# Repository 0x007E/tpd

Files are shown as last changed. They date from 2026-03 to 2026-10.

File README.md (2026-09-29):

  

# `TPD` - Touchpad



The `TPD` is a board with six single pads that are connected to a [AT42QT1070](#additional-information) touch sensor. The touch sensor can be connected to any microntroller over `TWI`. The board itself can be driven with a voltage from `1V8-5V` and controlled over the [AT42QTXXXX driver library](https://github.com/0x007E/drivers-touch-at42qtxxxx).

| Experience  | Level |
|:---|:---:|
| Soldering | ?% |
| Mechanical  | ?% |

# Downloads

| Type | File | Description |
|:---:|:---:|:---|
| Schematic | [pdf](https://github.com/0x007E/tpd/releases/latest/download/schematic.pdf) / [cadlab](https://cadlab.io/project/30134/main/files) | Schematic files |
| Board | [pdf](https://github.com/0x007E/tpd/releases/latest/download/pcb.pdf) / [cadlab](https://cadlab.io/project/30134/main/files) | Board file |
| Drill | [pdf](https://github.com/0x007E/tpd/releases/latest/download/drill.pdf) | Drill file |
| BoM | [xlsx](https://github.com/0x007E/tpd/releases/latest/download/bom.xlsx) / [html](https://github.com/0x007E/tpd/releases/latest/download/ibom.html) | Bill of Material as Excel/interactive HTML |
| PCB | [zip](https://github.com/0x007E/tpd/releases/latest/download/kicad.zip) / [tar](https://github.com/0x007E/tpd/releases/latest/download/kicad.tar.gz) | KiCAD/Gerber/BoM/Drill files |
| Mechanical | [zip](https://github.com/0x007E/tpd/releases/latest/download/freecad.zip) / [tar](https://github.com/0x007E/tpd/releases/latest/download/freecad.tar.gz) | FreeCAD/Housing and PCB (STEP/STL) files |

# Hardware

The pcb is created with `KiCAD`. All files are built with `github actions` so that they are ready for a production environment.

## PCB

The circuit board is populated on one side (Bottom). The best way for soldering the `SMD` components is within a vapor phase soldering system.

### Top Layer

Top Layer

### Bottom Layer

Bottom Layer

## Mechanical

The housing has a tolerance of `0.2mm` on each side of the case. So the pcb should fit perfectly in the housing. The tolerance can be modified with `FreeCAD` in the `Parameter` Spreadsheet.

### Assembled

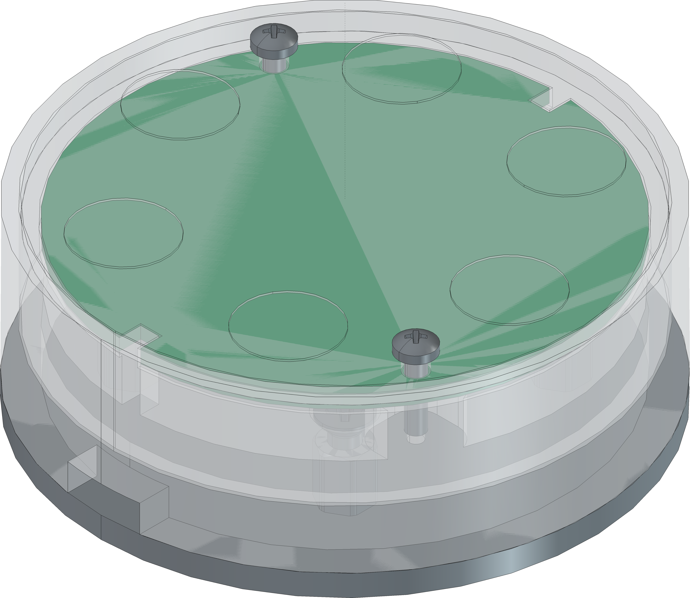
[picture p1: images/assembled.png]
Assembled


### Exploded

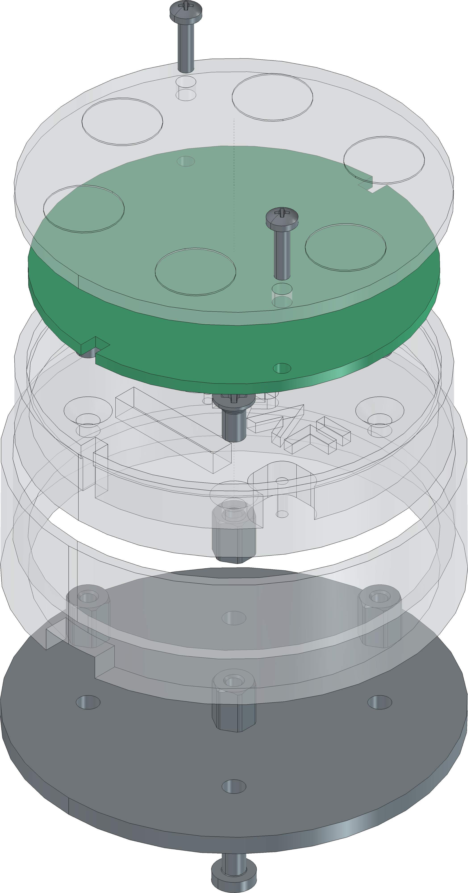
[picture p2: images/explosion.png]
Exploded


# Additional Information

| Type | Link | Description |
|:---:|:---:|:---|
| AT42QT1070 | [pdf](https://ww1.microchip.com/downloads/en/DeviceDoc/Atmel-9596-AT42-QTouch-BSW-AT42QT1070_Datasheet.pdf) | Seven-channel QTouch® Touch Sensor IC |

---

R. GAECHTER

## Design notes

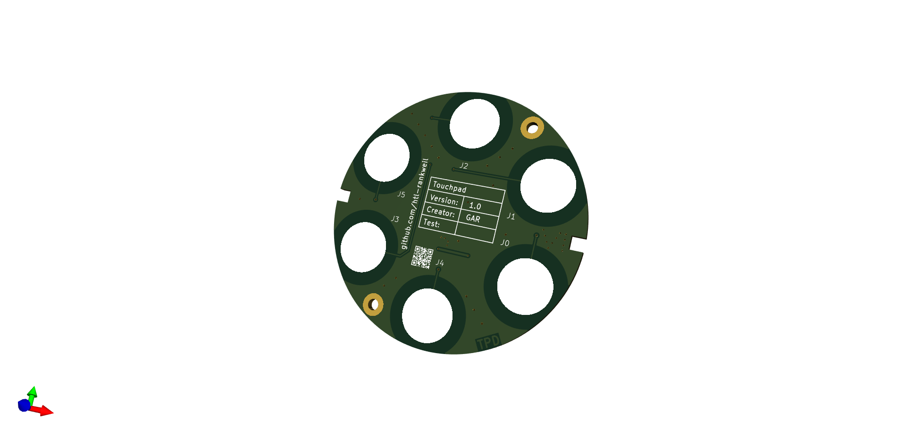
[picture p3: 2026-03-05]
pcb/TPD.png

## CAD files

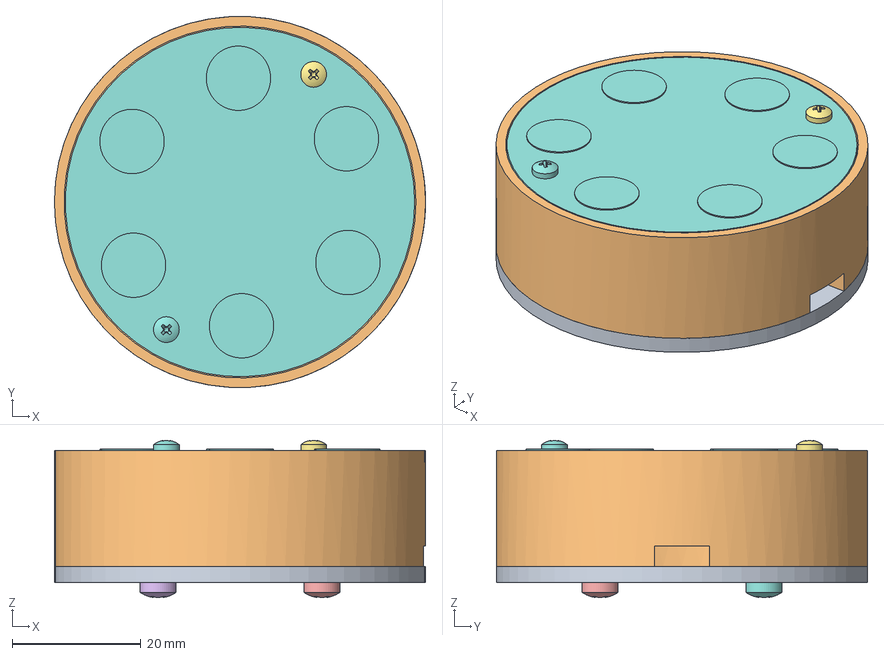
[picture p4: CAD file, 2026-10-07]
mechanical/housing.FCStd
57.6 x 57.6 x 24.4 mm
Pcb_84f1
R6_R_1206_3216Metric_b8ea6ec34850
R2_R_1206_3216Metric_b3acf86c6a30
R10_R_1206_3216Metric_fee79024a377
R8_R_1206_3216Metric_339db8180c64
C1_C_1206_3216Metric_12c8d903e841
R3_R_1206_3216Metric_83833871624d
R4_R_1206_3216Metric_442d5b8a35f1
R5_R_1206_3216Metric_4848958c9431
U1_SOIC-14_3.9x8.7mm_P1.27mm_35921325ff5e
R9_R_1206_3216Metric_88e3ba4c58bd
R7_R_1206_3216Metric_a49d56fa997f
J7_PinHeader_1x06_P254mm_Vertical_SMD_Pin1Left_1285e679425b
R1_R_1206_3216Metric_ab4ac080a6bd
Case
Acrylglass
Aluplate
M2.5x6x5-Spacer
M2.5x6x5-Spacer360
M2.5x6x5-Spacer361
M2.5x6x5-Spacer362
M2x8-Screw
M2x8-Screw006
M3x6-Screw
M3x6-Screw103
M3x6-Screw104
M3x6-Screw105
M3x5-Screw
M3x5-Screw106
M3x5-Screw107
M3x5-Screw108

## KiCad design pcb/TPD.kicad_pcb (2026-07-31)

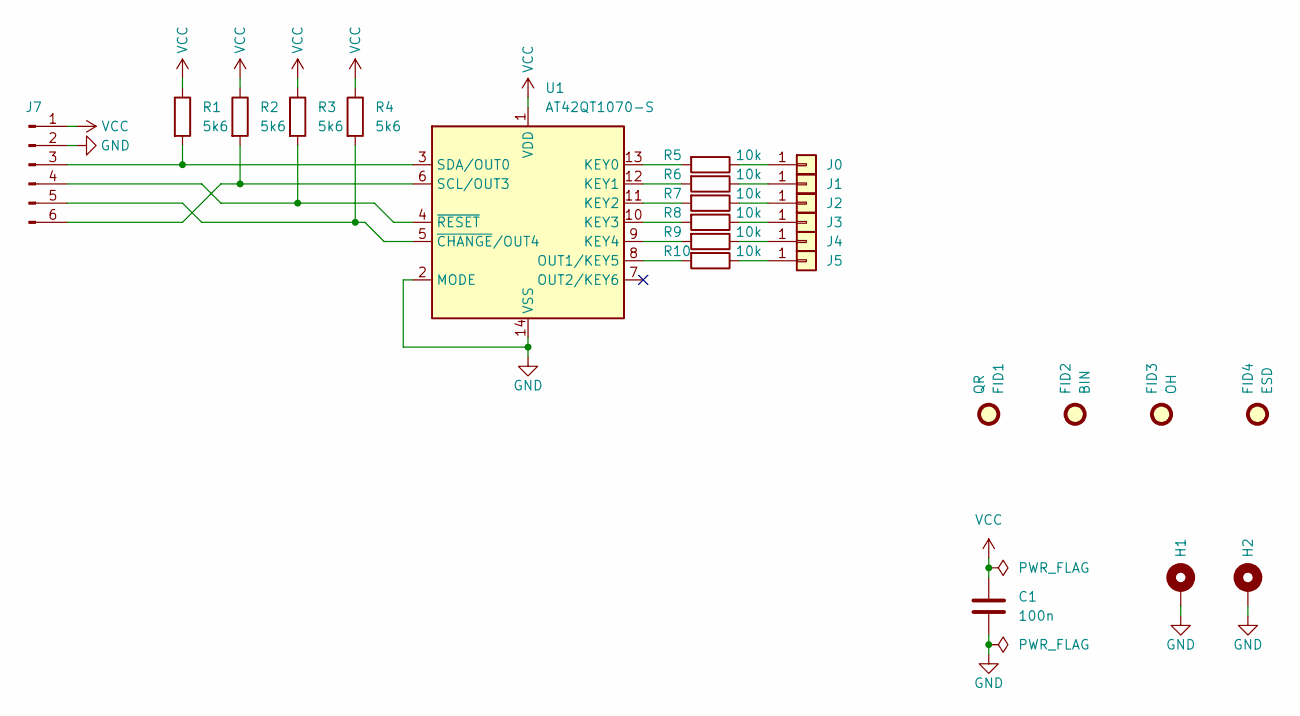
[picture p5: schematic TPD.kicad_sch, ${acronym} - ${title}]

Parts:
C1: 100n; C_1206_3216Metric
FID1: QR; QR_0x007e_very_small
FID2: BIN; WEEE-Logo_4.2x6mm_SilkScreen
FID3: OH; OSHW-Logo2_7.3x6mm_SilkScreen
FID4: ESD; ESD-Logo_6.6x6mm_SilkScreen
H1, H2: MountingHole_Pad; MountingHole_2.2mm_M2_Pad
J0, J1, J2, J3, J4, J5: Conn_01x01; Button_Round_Small
J7: Conn_01x06_Pin; PinHeader_1x06_P2.54mm_Vertical_SMD_Pin1Left
R1, R2, R3, R4: 5k6; R_1206_3216Metric
R5, R6, R7, R8, R9, R10: 10k; R_1206_3216Metric
U1: AT42QT1070-S; SOIC-14_3.9x8.7mm_P1.27mm

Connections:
GND: C1.2, H1.1, H2.1, J7.2, U1.2 (MODE), U1.14 (VSS)
unnamed: J0.1, R5.1
unnamed: J1.1, R6.1
unnamed: J2.1, R7.1
unnamed: J3.1, R8.1
unnamed: J4.1, R9.1
unnamed: J5.1, R10.1
unnamed: J7.3, R1.2, U1.3 (SDA/OUT0)
unnamed: J7.4, R3.2, U1.4 (~RESET)
unnamed: J7.5, R4.2, U1.5 (~CHANGE/OUT4)
unnamed: J7.6, R2.2, U1.6 (SCL/OUT3)
unnamed: R5.2, U1.13 (KEY0)
unnamed: R6.2, U1.12 (KEY1)
unnamed: R7.2, U1.11 (KEY2)
unnamed: R8.2, U1.10 (KEY3)
unnamed: R9.2, U1.9 (KEY4)
unnamed: R10.2, U1.8 (OUT1/KEY5)
VCC: C1.1, J7.1, R1.1, R2.1, R3.1, R4.1, U1.1 (VDD)

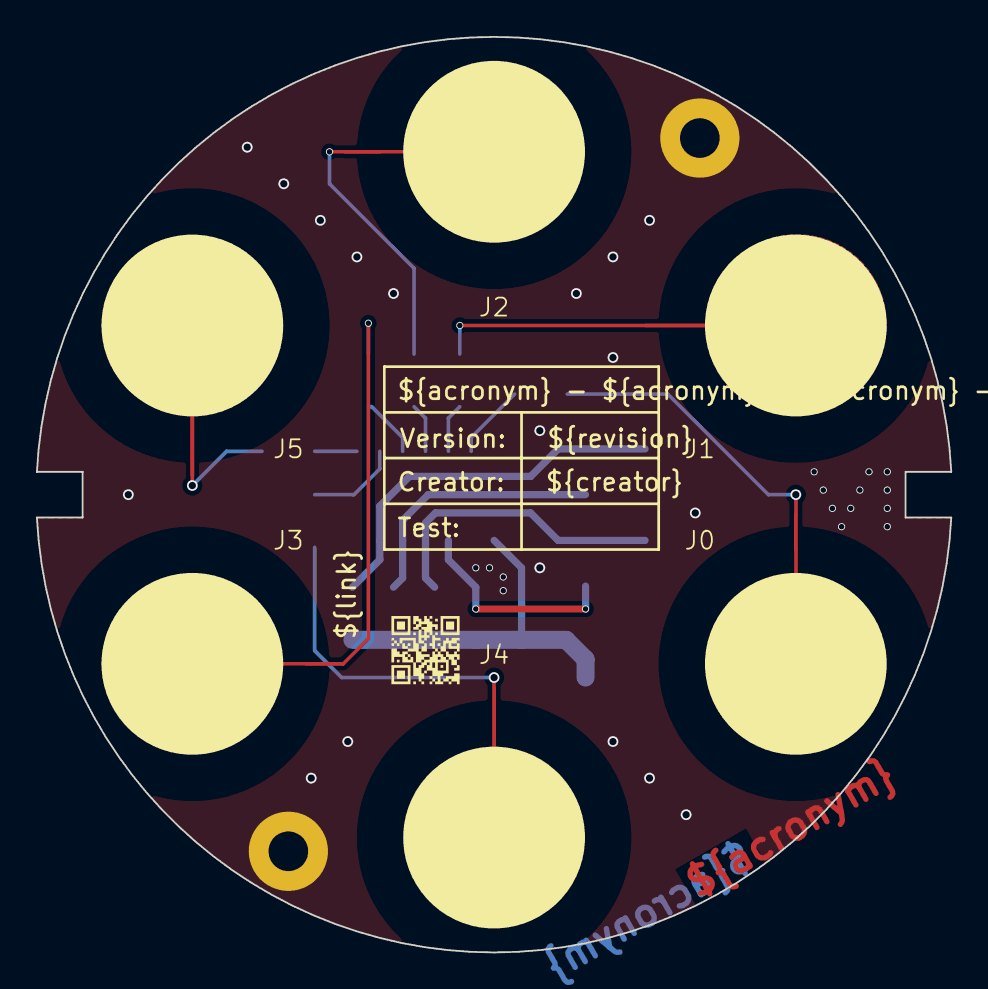
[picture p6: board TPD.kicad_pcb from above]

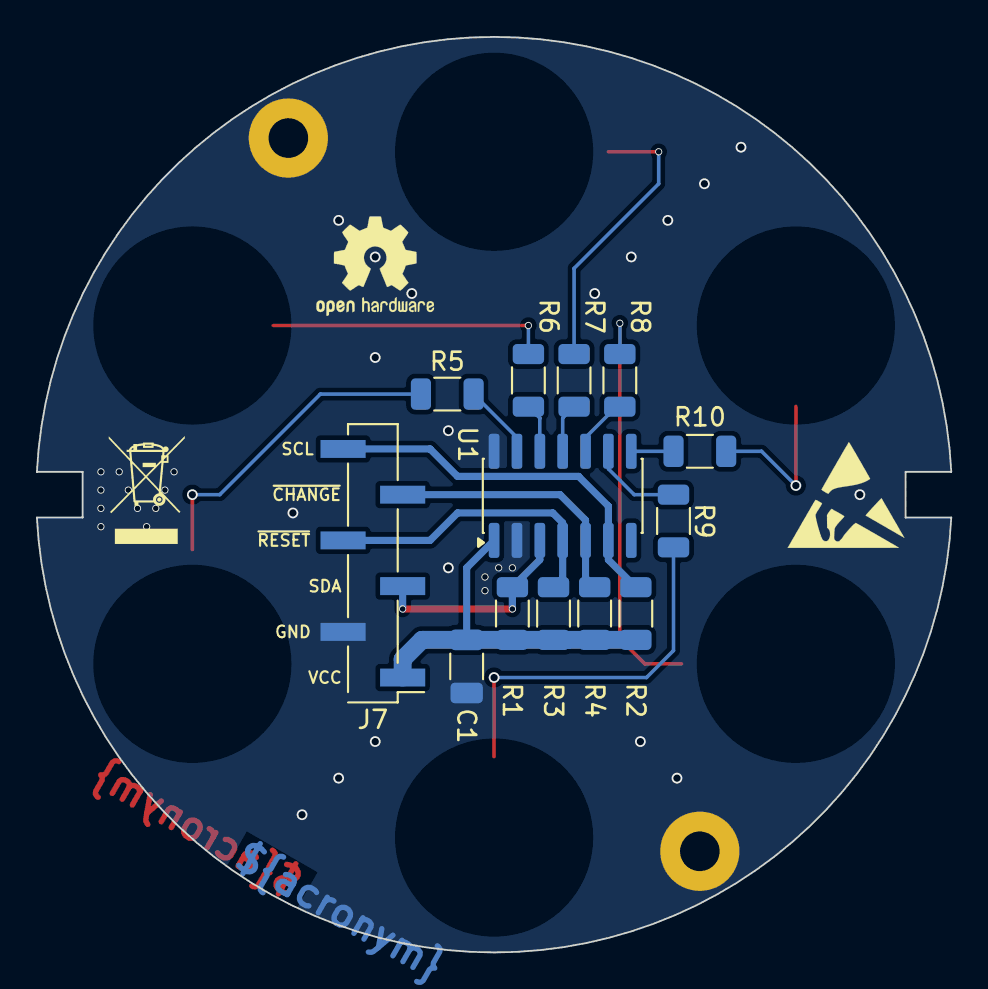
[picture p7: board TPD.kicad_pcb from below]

Board: 2 copper layers, 50.8 x 50.9 mm, 25 parts (16 on the bottom side), 18 nets.

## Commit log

2026-03-05 Add pcb layout
    [TPD.kicad_pcb, TPD.kicad_sch]
2026-03-05 Add missing vendors
    [TPD.kicad_pcb, TPD.kicad_sch]
2026-03-26 Add pin names to silkscreen
    [TPD.kicad_pcb]
2026-04-01 Add dimensioning
    [TPD.kicad_pcb]
2026-04-22 Adapt vendor(id)
    [TPD.kicad_pcb, TPD.kicad_sch]
2026-07-30 Update to KiCAD 9
    [TPD.kicad_pcb, TPD.kicad_sch]
2026-07-30 Rename/Add/Remove bom fields
    [TPD.kicad_pcb, TPD.kicad_sch]
2026-07-30 Add mechanical parts
    [housing.FCStd]
2026-07-30 Add assembly explosion
    [housing.FCStd]
2026-07-31 Optimize dimensioning
    [TPD.kicad_pcb]
2026-09-30 Roundup screw mounting platform
    [housing.FCStd]
2026-10-07 Adapt screws types
    [housing.FCStd]

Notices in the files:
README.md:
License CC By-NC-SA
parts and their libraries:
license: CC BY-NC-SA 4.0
